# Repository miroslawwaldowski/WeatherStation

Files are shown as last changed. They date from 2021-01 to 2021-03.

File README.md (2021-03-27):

# Weather station Wi-Fi / GSM 

Application view            |  Device view
:-------------------------:|:-------------------------:
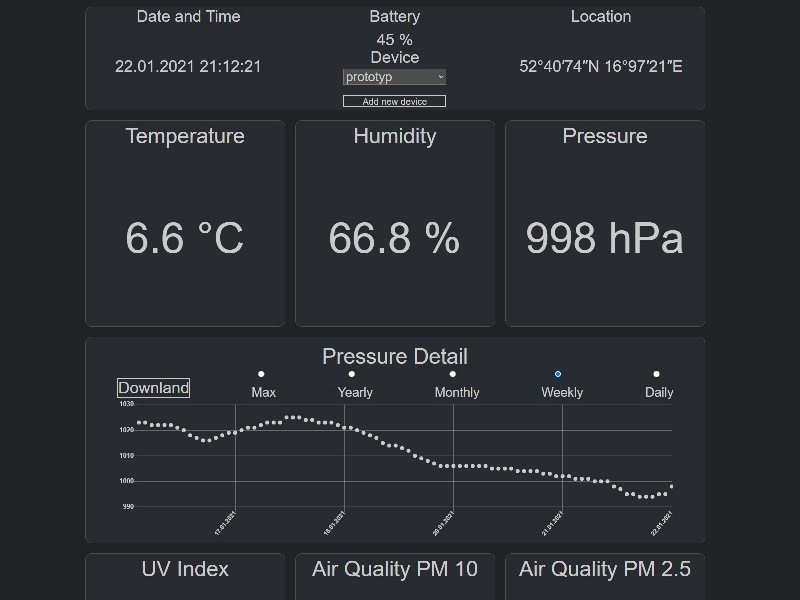
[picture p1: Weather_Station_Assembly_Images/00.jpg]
main app
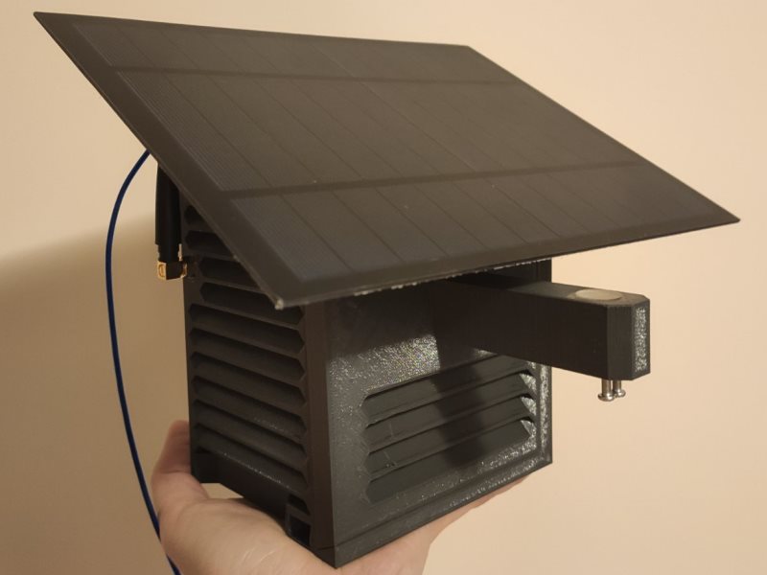
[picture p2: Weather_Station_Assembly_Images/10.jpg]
final view
 |  

## Introduction
The weather station project implemented as part of the Engineering Project at the Faculty of Mathematics and Computer Science of the University of Adam Mickiewicz in Poznań. The goal is to create a weather station based on an 8-bit microcontroller with a web application for collecting and presenting data. The station will have temperature, humidity, pressure, UV index and air quality sensors.
## Content

<p align="center">

folder / files          |  description
:-------------------------:|:-------------------------:
Tests/ |	Tests and results
Weather_Station_3D_Model/	| 3d model
Weather_Station_STL_file/	| 3d printing files
Weather_Station_Visualisation/	| 3d visualization
Weather_Station_Assembly_Images/	| Device assembly photos
Weather_Station_Wiring_Diagrams/	| Block and connections diagrams
client/	| React app
db/	| Database data schema and connection
device/	| Device software
index.js, app.js	| Node JS server

</p>

## Device

### Components
*	Arduino Nano board
*	communication module:
    * GSM - SIM800L EVB or  
    * WiFi - Wemos D1 Mini
*	temperature, humidity and pressure sensor BME280
*	Nova Fitness SDS011 dust sensor
*	UV sensor GUVA-S12SD
*	3.3V / 5V logic level converter
*	6V / 1A photovoltaic panel
*	NPN bipolar transistor, e.g. 2N2222
*	Schottky diode e.g. 1N5822
*	MT3608 step-up voltage converter
*	Li-Pol TP4056 charger with protection
*	2 x 18650 Li-Ion cells
*	4700uF capacitor
*	Universal double sided board

## Notes on device components

* SIM800L EVB module: due to the high instantaneous power consumption when establishing a connection to the GSM network, a capacitor with a capacity of at least 2000uF should be soldered to the module (photo below). Additionally, the module should have the [1418B05SIM800L24 firmware version](https://letmeknow.fr/blog/wp-content/uploads/2018/01/1418B05SIM800L24.zip). Software update instruction [link](http://www.raviyp.com/learn-how-to-update-the-firmware-of-your-sim800-modules/).

<p align="center">
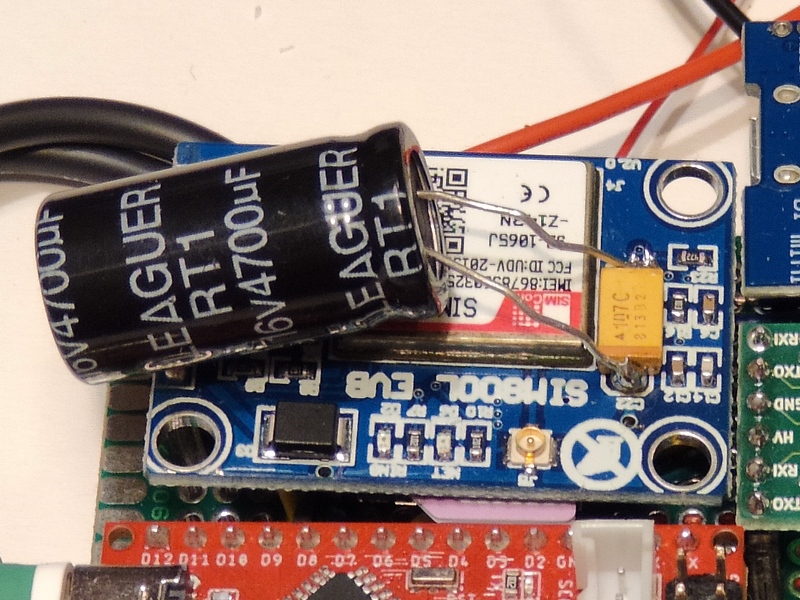
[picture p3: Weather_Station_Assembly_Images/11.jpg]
SIM800L
  
</p>

* Wemos D1 Mini module - the baud rate of serial communication data must be set to 9600. The change can be made with the command  `AT+CIOBAUD=9600`.  
* The MT3608 step-up voltage converter must have the output voltage set to 5V.

## Connection diagrams 
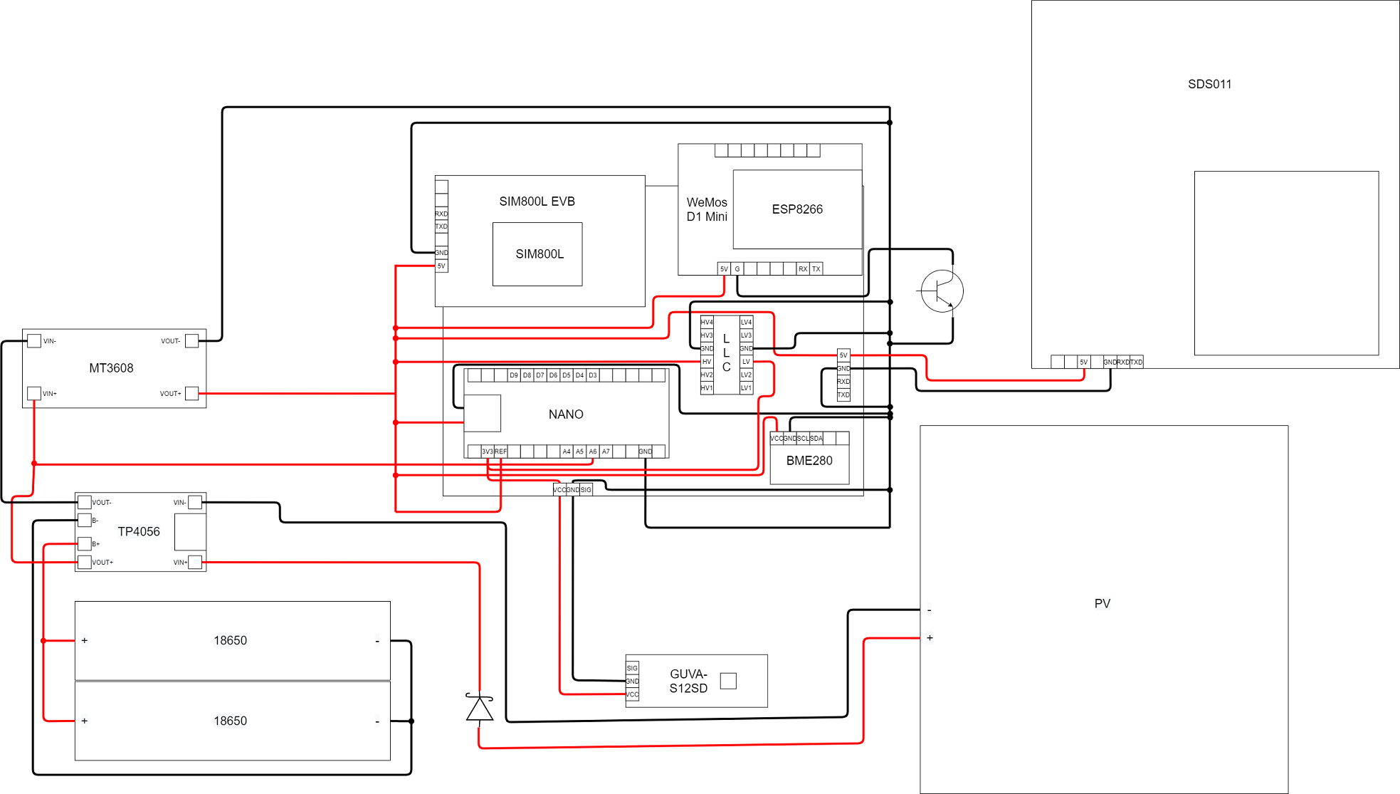
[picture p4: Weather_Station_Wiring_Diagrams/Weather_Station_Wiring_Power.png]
Wiring Power

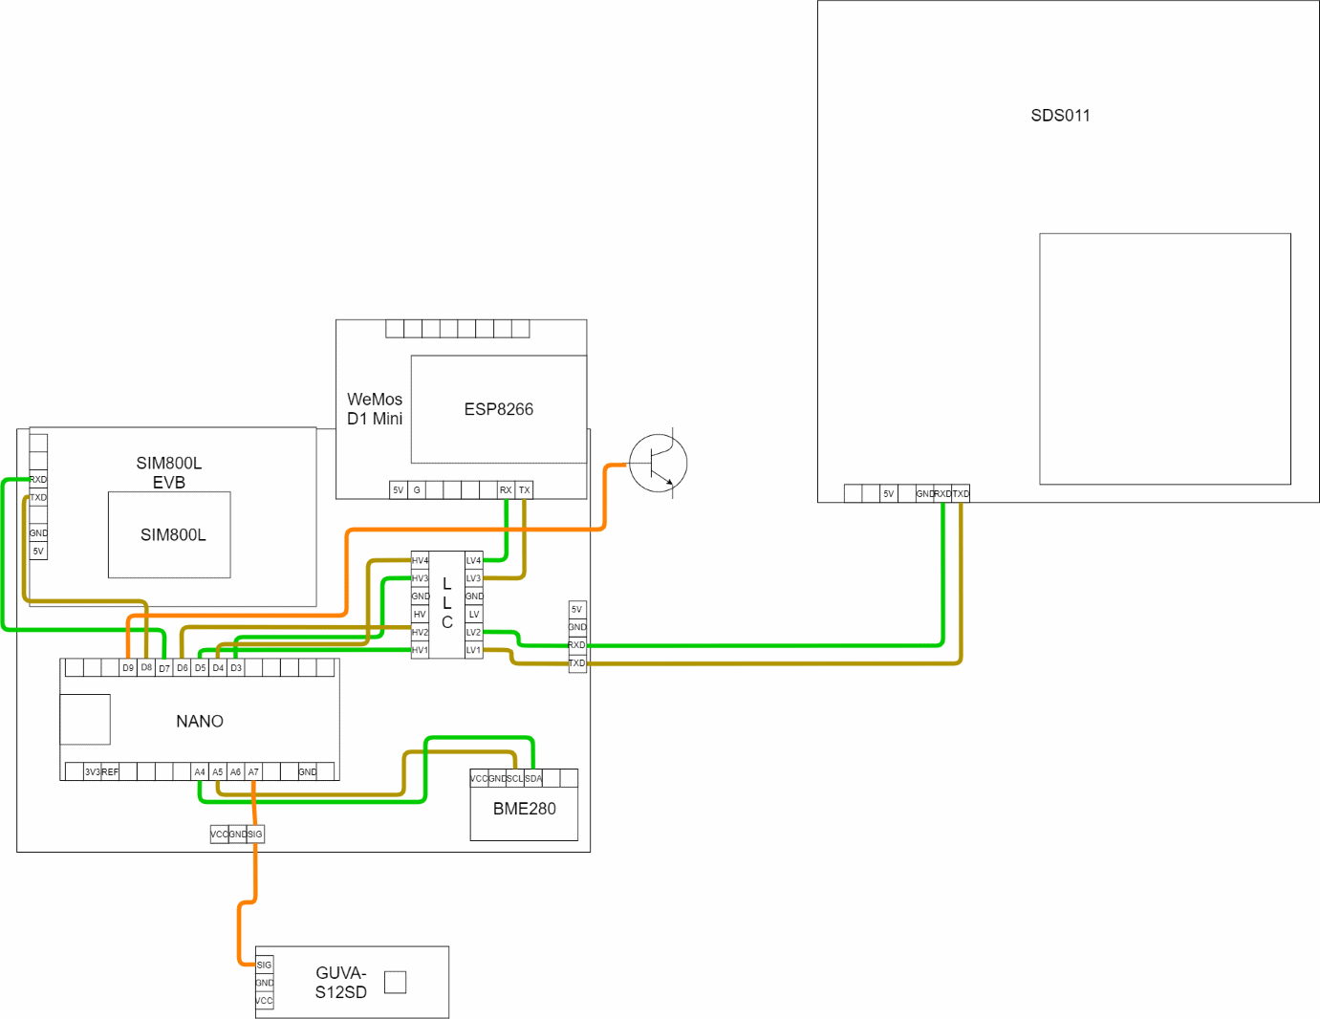
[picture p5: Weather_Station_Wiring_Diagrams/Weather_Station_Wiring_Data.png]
Wiring_Data


## Assembly of device elements

Picture of the assembled elements on the universal board according to the connection diagrams 
<p align="center">
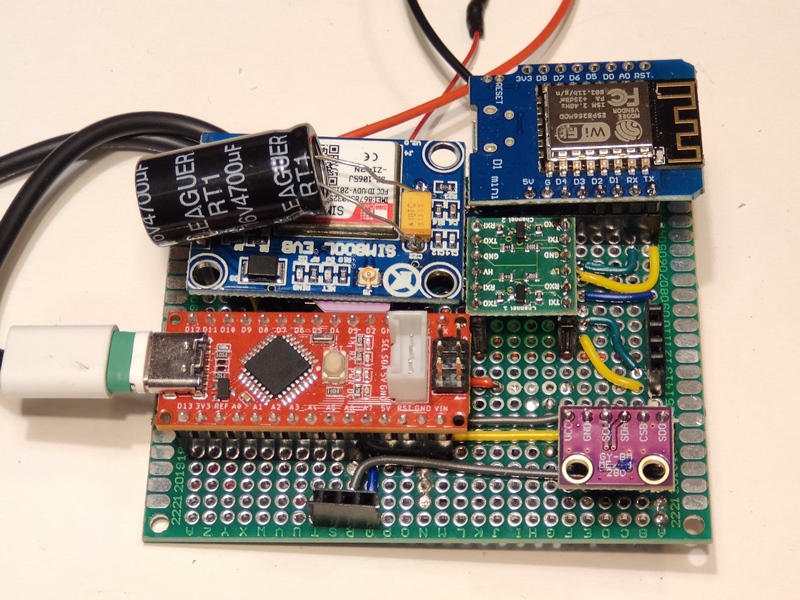
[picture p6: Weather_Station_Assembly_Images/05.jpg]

</p>

The next stages of assembly of elements in the case. The files for printing the case are in the Weather_Station_STL_file folder and the visualization of the arrangement of elements in the Weather_Station_Visualisation folder.

antenna assembly         |  battery assembly
:-------------------------:|:-------------------------:
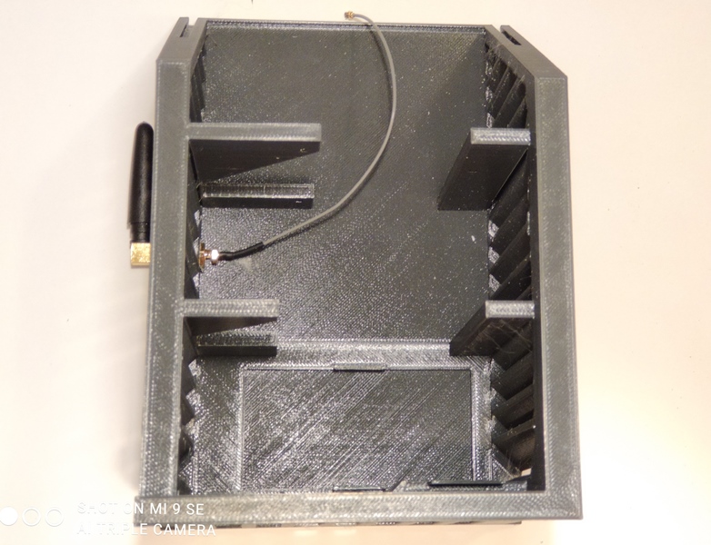
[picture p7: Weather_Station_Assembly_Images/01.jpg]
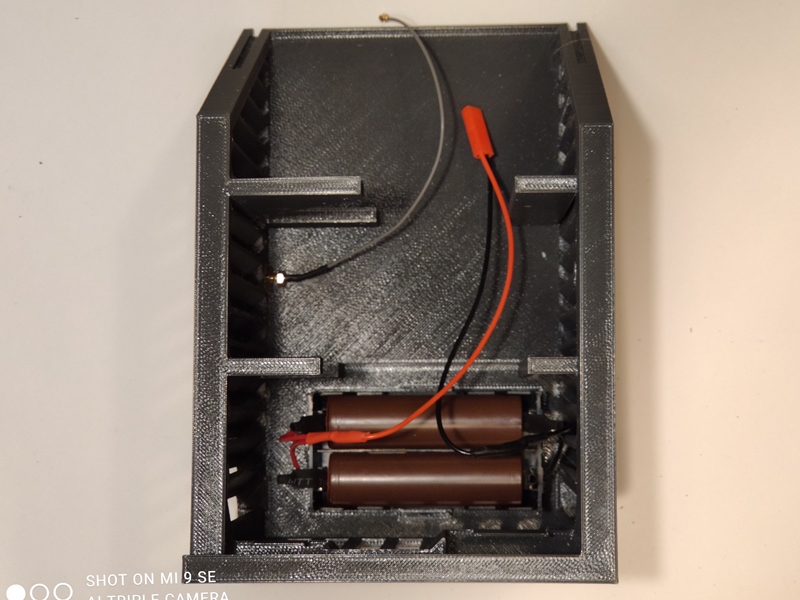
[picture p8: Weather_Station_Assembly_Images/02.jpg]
 |  
assembly of the Li-Po charger            |  voltage converter assembly
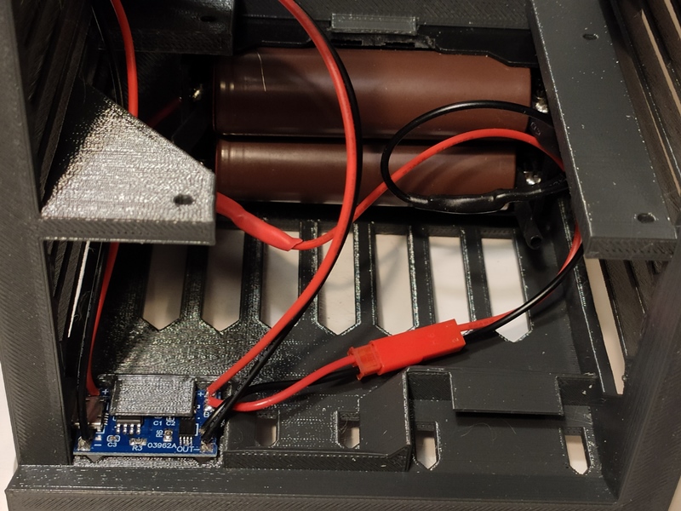
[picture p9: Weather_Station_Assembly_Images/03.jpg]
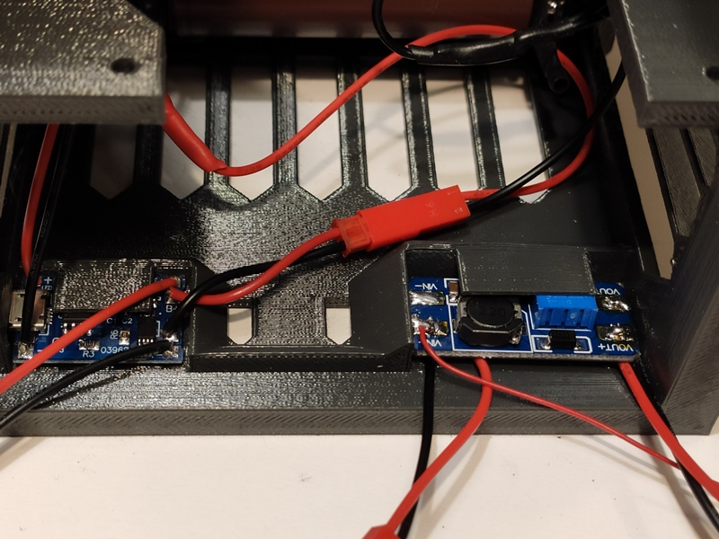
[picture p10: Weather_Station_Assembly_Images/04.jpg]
 |  
assembly of the plate with mounted elements             |  UV sensor assembly
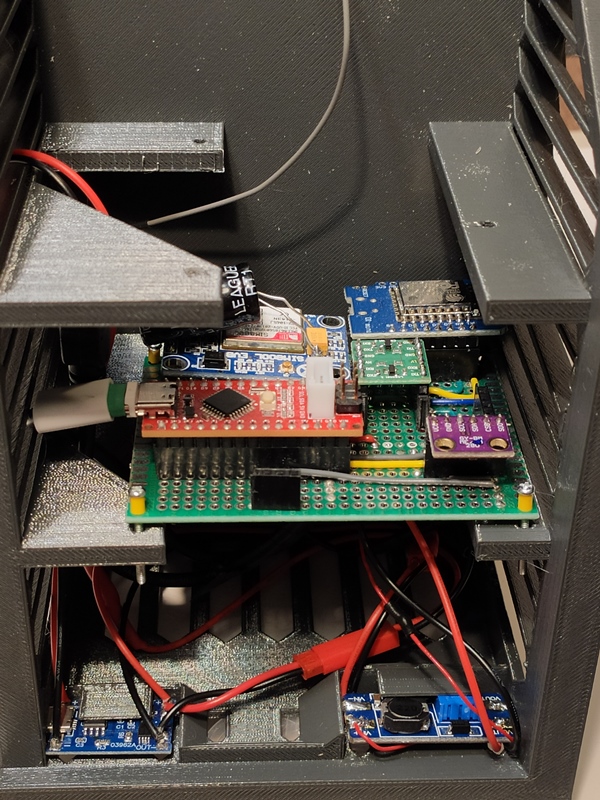
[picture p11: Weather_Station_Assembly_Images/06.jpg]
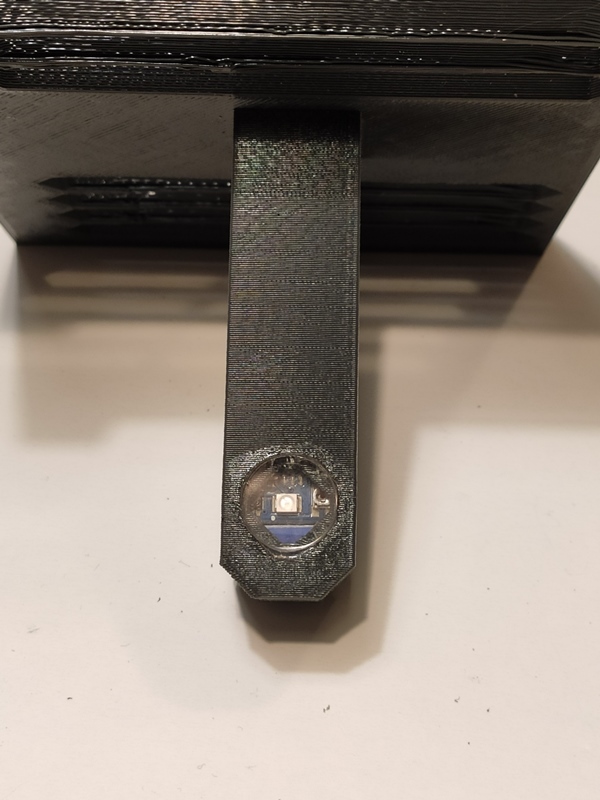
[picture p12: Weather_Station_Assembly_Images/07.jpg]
 |  
installation of a photovoltaic panel            |  Device view
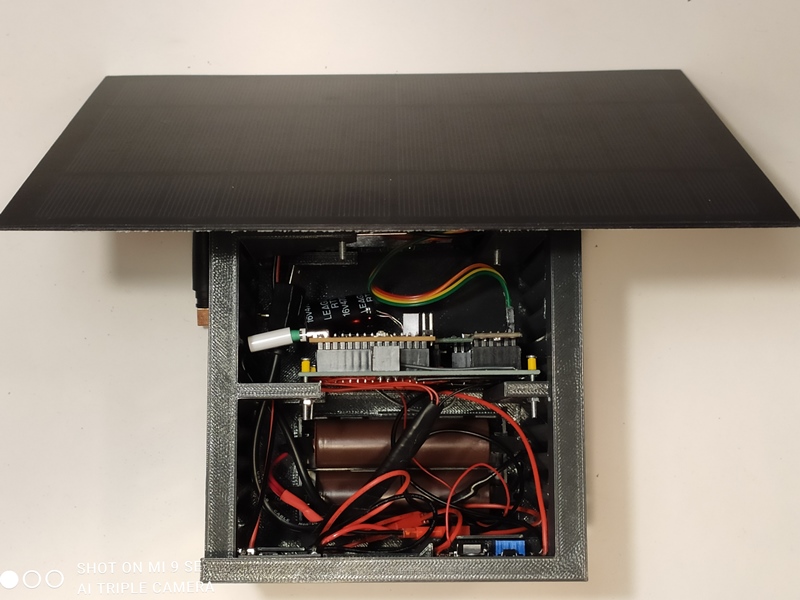
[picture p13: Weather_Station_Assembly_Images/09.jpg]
 |  

## Software
### Block diagram

<p align="center">
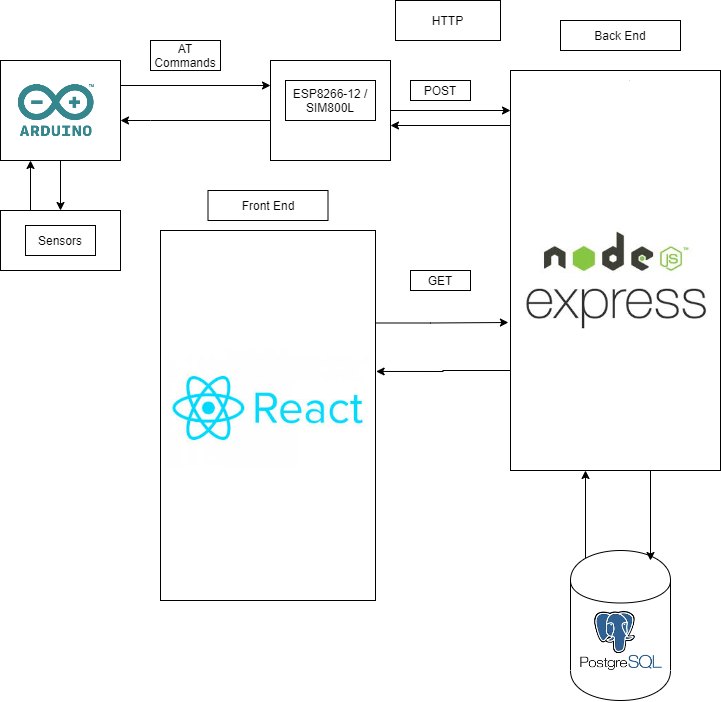
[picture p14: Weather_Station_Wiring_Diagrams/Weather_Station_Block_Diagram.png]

</p>

### Relational PostgreSQL database
ERD entity relationship diagram

<p align="center">
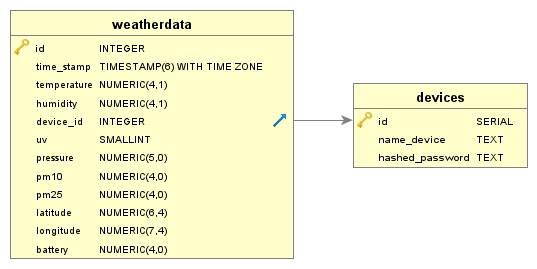
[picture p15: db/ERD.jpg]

</p>

`database.sql` file contains commands to generate SQL database.
An example of installing a database on an ElephantSQL server is available at [this link](https://www.learmoreseekmore.com/2020/09/postgresql-elephantsql-cloudserv.html).

## Mapbox Token

In order for maps with the device location to be displayed correctly in the application, you must obtain a token from the Mapbox website.
To do this, create a free account at [https://www.mapbox.com/](https://www.mapbox.com/).
After registering, your token will be visible in the "Account" tab, which will be needed to configure the React application.

## Installation of React application software and Node js server on the example of installation on the Heroku cloud platform

First, you need to clone the repository  
`$ git clone https://github.com/miroslawwaldowski/WeatherStation`  
Then create an account at [https://www.heroku.com/](https://www.heroku.com/) and install [Heroku CLI](https://devcenter.heroku.com/articles/heroku-command-line).  
After installation, go to the main application folder and log in to the Heroku   
`$ heroku login`  
The application on the server is created with the command  
`$ heroku create example`  
Where `example` is the name of our application. The application will be available at https://example.herokuapp.com/  
We add a remote Herock repository with the command   
`$ heroku git:remote -a example`  
Where `example` is the name of our application  
Finally, we approve the changes and send them  
`$ git add .`  
`$ git commit -am "version 1.0"`  
`$ git push heroku master`  
After completing the steps, the application should install on the website.  

## Environment variables for the app:

`DB_DATABASE=database name`  
`DB_HOST=database server`  
`DB_PASSWORD=database password`  
`DB_PORT=port to database`  
`DB_USER=database user`  
`REACT_APP_MAPBOX_TOKEN=token from Mapbox`  

## Installing the software on the Arduino Nano.

Before installing the software, the following libraries should be installed to the Arduino IDE 
[LowPower](https://github.com/rocketscream/Low-Power) and [Adafruit_BME280_Library](https://github.com/adafruit/Adafruit_BME280_Library) and configure the source code of the `device/app.ino` :

/*If DEBUG is true, it prints answers from the modem to Serial monitor*/  
`#define DEBUG true`  
/*If GSM is true, connect via GSM/GPRS, if false, connect via WiFi*/  
`#define GSM_MODE true`  
// configuration of the application address and port  
`const char server[] PROGMEM = {"your-application.com"};`  
`int port = 80;`  
// Wi-Fi configuration  
`const char ssid_WiFI[] PROGMEM = {"YOUR_SSID_NAME"};`  
`const char password_WiFI[] PROGMEM = {"YOUR_PASSWORD_TO_WIFI"};`  
// GPRS APN configuration of the mobile network  
`const char gprs_apn[] PROGMEM = {"\"INTERNET\""};`  
// data configuration of this device  
`const char device_name[] PROGMEM = {"OWN_DEVICE_NAME"};`  
`const char server_password[] PROGMEM = {"OWN_PASSWORD_ DEVICE"};`  
// device height above sea level in in meters for calculating relative pressure  
`int height_above_sea_level = 80;`  

## Final configuration.

After installing the software on the arduino board, the previously configured device should be added to the web application by entering the website of your application and clicking the `add new device` button. In the form that will appear, enter exactly the device name and password that were given in the device data configuration.

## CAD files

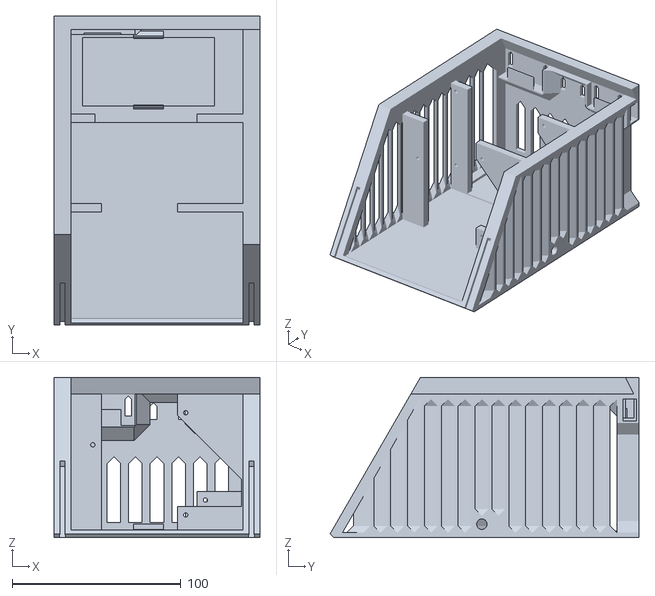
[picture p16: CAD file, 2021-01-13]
Weather_Station_STL_file/Weather_Station_ Body.stl
122.0 x 183.0 x 95.0

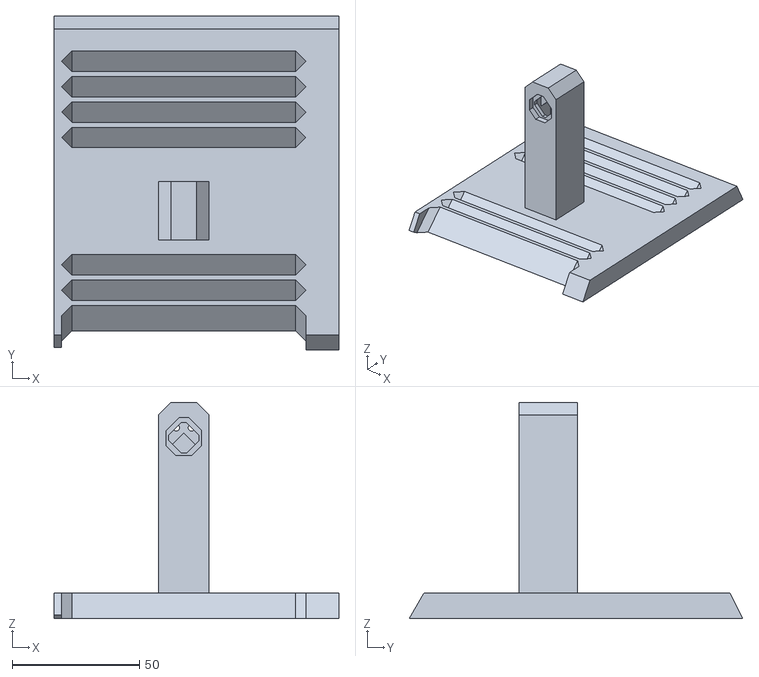
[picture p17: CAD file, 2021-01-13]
Weather_Station_STL_file/Weather_Station_Door.stl
112.0 x 131.2 x 85.0

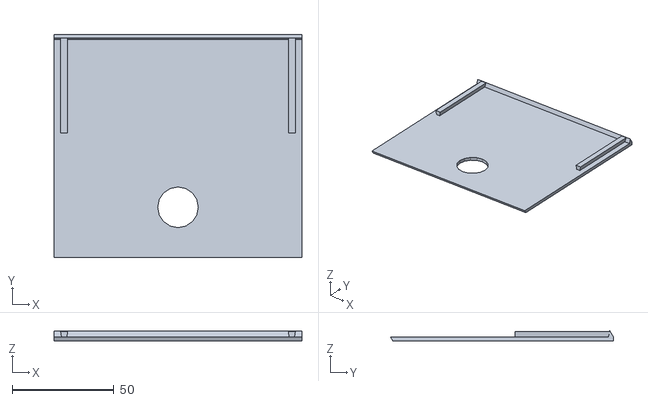
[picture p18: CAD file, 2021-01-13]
Weather_Station_STL_file/Weather_Station_ Roof.stl
122.0 x 109.7 x 5.00

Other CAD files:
Weather_Station_3D_Model/Weather_Station.skp

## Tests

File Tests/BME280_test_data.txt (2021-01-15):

16:27:54.086 -> Temperature C = 
16:27:54.086 -> 24.93
16:27:55.101 -> 24.93
16:27:56.097 -> 24.93
16:27:57.080 -> 24.93
16:27:58.103 -> 24.93
16:27:59.091 -> 24.93
16:28:00.078 -> 24.93
16:28:01.102 -> 24.92
16:28:02.134 -> 24.92
16:28:03.080 -> 24.92
16:28:04.119 -> 24.92
16:28:05.128 -> 24.93
16:28:06.103 -> 24.93
16:28:07.103 -> 24.93
16:28:08.132 -> 24.93
16:28:09.148 -> 24.93
16:28:10.132 -> 24.93
16:28:11.111 -> 24.92
16:28:12.136 -> 24.92
16:28:13.126 -> 24.92
16:28:14.146 -> 24.92
16:28:15.113 -> 24.92
16:28:16.153 -> 24.91
16:28:17.124 -> 24.91
16:28:18.142 -> 24.91
16:28:19.131 -> 24.91
16:28:20.128 -> 24.90
16:28:21.154 -> 24.89
16:28:22.136 -> 24.89
16:28:23.155 -> 24.89
16:28:24.148 -> 24.89
16:28:25.152 -> 24.88
16:28:26.167 -> 24.89
16:28:27.120 -> 24.88
16:28:28.166 -> 24.88
16:28:29.143 -> 24.87
16:28:30.139 -> 24.87
16:28:31.171 -> 24.87
16:28:32.156 -> 24.87
16:28:33.179 -> 24.87
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
16:29:34.266 -> Humidity % = 
16:29:34.266 -> 31.08
16:29:35.277 -> 31.09
16:29:36.279 -> 31.04
16:29:37.273 -> 31.03
16:29:38.283 -> 31.08
16:29:39.293 -> 31.10
16:29:40.286 -> 31.10
16:29:41.291 -> 31.11
16:29:42.310 -> 31.23
16:29:43.302 -> 31.26
16:29:44.322 -> 31.27
16:29:45.298 -> 31.25
16:29:46.293 -> 31.21
16:29:47.303 -> 31.27
16:29:48.300 -> 31.20
16:29:49.323 -> 31.16
16:29:50.319 -> 31.13
16:29:51.296 -> 31.13
16:29:52.334 -> 31.14
16:29:53.308 -> 31.16
16:29:54.296 -> 31.19
16:29:55.319 -> 31.25
16:29:56.329 -> 31.29
16:29:57.324 -> 31.35
16:29:58.326 -> 31.41
16:29:59.340 -> 31.48
16:30:00.351 -> 32.06
16:30:01.450 -> 32.36
16:30:02.327 -> 32.61
16:30:03.318 -> 32.56
16:30:04.341 -> 32.57
16:30:05.361 -> 32.47
16:30:06.331 -> 32.42
16:30:07.368 -> 32.36
16:30:08.374 -> 32.30
16:30:09.367 -> 32.42
16:30:10.346 -> 32.60
16:30:11.370 -> 32.48
16:30:12.349 -> 32.24
16:30:13.372 -> 32.03
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
16:31:14.526 -> Pressure hPa = 
16:31:14.526 -> 1009.23
16:31:15.504 -> 1009.24
16:31:16.542 -> 1009.26
16:31:17.520 -> 1009.27
16:31:18.510 -> 1009.27
16:31:19.540 -> 1009.25
16:31:20.539 -> 1009.26
16:31:21.519 -> 1009.28
16:31:22.520 -> 1009.29
16:31:23.537 -> 1009.29
16:31:24.521 -> 1009.31
16:31:25.526 -> 1009.35
16:31:26.537 -> 1009.30
16:31:27.562 -> 1009.29
16:31:28.578 -> 1009.27
16:31:29.563 -> 1009.29
16:31:30.559 -> 1009.28
16:31:31.573 -> 1009.30
16:31:32.576 -> 1009.31
16:31:33.573 -> 1009.31
16:31:34.587 -> 1009.31
16:31:35.571 -> 1009.30
16:31:36.605 -> 1009.25
16:31:37.580 -> 1009.29
16:31:38.604 -> 1009.28
16:31:39.584 -> 1009.26
16:31:40.600 -> 1009.28
16:31:41.580 -> 1009.27
16:31:42.610 -> 1009.31
16:31:43.594 -> 1009.27
16:31:44.619 -> 1009.27
16:31:45.604 -> 1009.31
16:31:46.620 -> 1009.29
16:31:47.605 -> 1009.26
16:31:48.635 -> 1009.29
16:31:49.620 -> 1009.29
16:31:50.605 -> 1009.26
16:31:51.638 -> 1009.30
16:31:52.622 -> 1009.25
16:31:53.610 -> 1009.26
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

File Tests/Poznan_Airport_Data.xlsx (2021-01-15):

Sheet: Arkusz1
Time | Temperature | Humidity | Pressure
 | C | % | hPa
2021-01-12 01:00 | 0 | 74 | 1010
2021-01-12 02:00 | 0 | 80 | 1008
2021-01-12 02:30 | 0 | 74 | 1008
2021-01-12 03:00 | 0 | 80 | 1008
2021-01-12 03:01 | 0 | 80 | 1008
2021-01-12 03:30 | 0 | 80 | 1007
2021-01-12 04:00 | 0 | 80 | 1006
2021-01-12 04:30 | 0 | 80 | 1006
2021-01-12 05:00 | 0 | 80 | 1005
2021-01-12 05:01 | 0 | 80 | 1005
2021-01-12 05:30 | 1 | 75 | 1005
2021-01-12 06:00 | 1 | 75 | 1005
2021-01-12 06:30 | 1 | 80 | 1004
2021-01-12 07:00 | 1 | 80 | 1004
2021-01-12 07:31 | 1 | 80 | 1004
2021-01-12 07:30 | 1 | 80 | 1004
2021-01-12 08:00 | 0 | 86 | 1004
2021-01-12 08:30 | 0 | 93 | 1003
2021-01-12 09:00 | 0 | 93 | 1003
2021-01-12 09:30 | 0 | 93 | 1003
2021-01-12 10:00 | 0 | 93 | 1003
2021-01-12 10:30 | 0 | 93 | 1002
2021-01-12 10:31 | 0 | 93 | 1002
2021-01-12 11:00 | 0 | 93 | 1002
2021-01-12 11:30 | 0 | 93 | 1001
2021-01-12 12:00 | 0 | 93 | 1001
2021-01-12 12:30 | 0 | 93 | 1001
2021-01-12 12:31 | 0 | 93 | 1001
2021-01-12 13:00 | 0 | 100 | 1000
2021-01-12 13:30 | 0 | 100 | 1000
2021-01-12 14:00 | 0 | 100 | 1000
2021-01-12 14:01 | 0 | 100 | 1000
2021-01-12 14:31 | 0 | 100 | 1000
2021-01-12 14:30 | 0 | 100 | 1000
2021-01-12 15:00 | 0 | 100 | 1000
2021-01-12 15:31 | 0 | 100 | 1000
2021-01-12 16:00 | 0 | 100 | 1000
2021-01-12 16:30 | 0 | 100 | 1000
2021-01-12 17:00 | 0 | 100 | 999
2021-01-12 17:01 | 0 | 100 | 999
2021-01-12 17:30 | 0 | 100 | 999
2021-01-12 18:00 | 0 | 100 | 1000
2021-01-12 18:30 | 0 | 100 | 1000
2021-01-12 19:00 | 0 | 100 | 1000
2021-01-12 19:30 | 0 | 100 | 1001
2021-01-12 20:00 | 0 | 100 | 1001
2021-01-12 20:30 | 0 | 100 | 1002
2021-01-12 21:00 | 0 | 93 | 1002
2021-01-12 21:30 | 0 | 93 | 1002
2021-01-12 22:01 | 0 | 93 | 1002
2021-01-12 22:00 | 0 | 93 | 1002
2021-01-12 22:31 | 0 | 93 | 1003
2021-01-12 22:30 | 0 | 93 | 1003
2021-01-12 23:00 | 0 | 93 | 1002
2021-01-12 23:30 | 0 | 93 | 1003
2021-01-13 00:01 | 0 | 100 | 1003
2021-01-13 | 0 | 100 | 1003
2021-01-13 00:30 | 0 | 100 | 1003
2021-01-13 00:31 | 0 | 100 | 1003
2021-01-13 01:00 | 0 | 100 | 1003
2021-01-13 01:30 | 0 | 93 | 1004
2021-01-13 02:00 | 0 | 93 | 1004
2021-01-13 02:30 | 0 | 93 | 1004
2021-01-13 03:01 | 0 | 93 | 1004
2021-01-13 03:00 | 0 | 93 | 1004
2021-01-13 03:30 | 0 | 93 | 1005
2021-01-13 04:00 | 0 | 93 | 1005
2021-01-13 04:30 | 0 | 93 | 1005
2021-01-13 05:01 | 0 | 93 | 1005
2021-01-13 05:00 | 0 | 93 | 1005
2021-01-13 05:30 | 0 | 93 | 1005
2021-01-13 05:31 | 0 | 93 | 1005
2021-01-13 06:00 | 0 | 93 | 1005
2021-01-13 06:30 | 0 | 93 | 1005
2021-01-13 07:00 | 0 | 93 | 1005
2021-01-13 07:30 | 0 | 100 | 1006
2021-01-13 08:00 | 0 | 100 | 1006
2021-01-13 08:30 | 0 | 100 | 1006
2021-01-13 09:00 | 1 | 86 | 1006
2021-01-13 09:30 | 1 | 86 | 1006
2021-01-13 10:00 | 1 | 86 | 1006
2021-01-13 10:30 | 1 | 93 | 1006
2021-01-13 11:00 | 1 | 93 | 1006
2021-01-13 11:30 | 1 | 93 | 1006
2021-01-13 12:00 | 1 | 93 | 1005
2021-01-13 12:30 | 1 | 93 | 1005
2021-01-13 13:00 | 1 | 93 | 1005
2021-01-13 13:30 | 1 | 93 | 1005
2021-01-13 14:00 | 1 | 93 | 1005
2021-01-13 14:01 | 1 | 93 | 1005
2021-01-13 14:30 | 1 | 93 | 1005
2021-01-13 14:31 | 1 | 93 | 1005
2021-01-13 15:00 | 1 | 93 | 1005
2021-01-13 15:30 | 1 | 93 | 1004
2021-01-13 16:00 | 1 | 93 | 1004
2021-01-13 16:30 | 1 | 93 | 1004
2021-01-13 17:00 | 1 | 93 | 1003
2021-01-13 17:30 | 1 | 93 | 1003
2021-01-13 18:00 | 1 | 93 | 1003
2021-01-13 18:30 | 1 | 93 | 1002
2021-01-13 19:00 | 1 | 93 | 1002
2021-01-13 19:30 | 0 | 100 | 1001
2021-01-13 20:00 | 0 | 100 | 1001
2021-01-13 20:01 | 0 | 100 | 1001
2021-01-13 20:30 | 0 | 100 | 1000
2021-01-13 21:00 | 0 | 100 | 1000
2021-01-13 21:30 | 0 | 100 | 1000
2021-01-13 22:00 | 0 | 100 | 1000
2021-01-13 22:01 | 0 | 100 | 1000
2021-01-13 22:30 | 0 | 100 | 1000
2021-01-13 23:00 | 0 | 100 | 1000
2021-01-13 23:30 | 0 | 100 | 1000
2021-01-14 | 0 | 100 | 1000
2021-01-14 00:30 | 0 | 100 | 1000
2021-01-14 01:00 | 0 | 100 | 1001
2021-01-14 01:30 | 0 | 100 | 1001
2021-01-14 02:00 | 0 | 100 | 1001
2021-01-14 02:30 | 0 | 100 | 1002
2021-01-14 03:00 | 0 | 100 | 1002
2021-01-14 04:01 | 0 | 100 | 1003
2021-01-14 04:00 | 0 | 100 | 1003
2021-01-14 04:30 | 0 | 100 | 1004
2021-01-14 05:00 | 0 | 100 | 1004
2021-01-14 05:30 | 0 | 100 | 1005
2021-01-14 06:00 | 0 | 100 | 1006
2021-01-14 06:30 | 0 | 100 | 1007
2021-01-14 07:00 | 0 | 100 | 1007
2021-01-14 07:30 | 0 | 100 | 1008
2021-01-14 08:00 | 0 | 100 | 1009
2021-01-14 08:01 | 0 | 100 | 1009
2021-01-14 08:30 | 0 | 100 | 1010
2021-01-14 09:00 | 0 | 93 | 1010
2021-01-14 09:30 | 0 | 93 | 1011
2021-01-14 10:00 | 0 | 93 | 1011
2021-01-14 10:30 | 0 | 93 | 1012
2021-01-14 11:00 | 0 | 93 | 1012
2021-01-14 11:30 | 0 | 93 | 1012
2021-01-14 12:00 | 0 | 93 | 1012
2021-01-14 12:30 | 0 | 93 | 1012
2021-01-14 13:00 | 0 | 93 | 1012
2021-01-14 13:30 | 0 | 100 | 1013
2021-01-14 14:00 | 0 | 100 | 1013
2021-01-14 14:01 | 0 | 100 | 1013
2021-01-14 15:00 | 0 | 100 | 1014
2021-01-14 15:30 | 0 | 93 | 1015
2021-01-14 16:00 | 0 | 93 | 1015
2021-01-14 16:30 | 0 | 93 | 1015
2021-01-14 17:00 | 0 | 93 | 1015
2021-01-14 17:30 | 0 | 93 | 1015
2021-01-14 18:00 | 0 | 93 | 1016
2021-01-14 18:30 | 0 | 93 | 1016
2021-01-14 18:31 | 0 | 93 | 1016
2021-01-14 19:00 | -1 | 93 | 1016
2021-01-14 19:30 | -1 | 93 | 1016
2021-01-14 20:00 | -1 | 93 | 1017
2021-01-14 20:30 | -1 | 86 | 1017
2021-01-14 21:00 | -1 | 86 | 1017
2021-01-14 21:30 | -1 | 93 | 1017
2021-01-14 22:00 | -1 | 93 | 1017
2021-01-14 22:30 | -1 | 100 | 1017
2021-01-14 23:00 | -1 | 100 | 1017
2021-01-14 23:30 | -1 | 100 | 1017
2021-01-15 | -1 | 100 | 1017
2021-01-15 00:01 | -1 | 100 | 1017
2021-01-15 01:00 | -1 | 100 | 1017
2021-01-15 01:30 | -1 | 100 | 1017
2021-01-15 02:00 | -1 | 93 | 1018
2021-01-15 02:30 | -1 | 93 | 1017
2021-01-15 03:00 | -1 | 93 | 1018
2021-01-15 03:30 | -1 | 93 | 1018
2021-01-15 04:01 | -2 | 100 | 1018
2021-01-15 04:00 | -2 | 100 | 1018
2021-01-15 04:30 | -2 | 100 | 1018
2021-01-15 05:00 | -2 | 100 | 1018
2021-01-15 05:30 | -2 | 100 | 1018
2021-01-15 06:00 | -2 | 100 | 1018
2021-01-15 06:31 | -2 | 100 | 1018
2021-01-15 06:30 | -2 | 100 | 1018
2021-01-15 07:00 | -2 | 93 | 1018
2021-01-15 07:30 | -2 | 100 | 1018
2021-01-15 08:00 | -2 | 100 | 1019
2021-01-15 08:30 | -1 | 93 | 1018
2021-01-15 09:00 | -1 | 93 | 1019
2021-01-15 09:30 | -1 | 93 | 1019
2021-01-15 10:00 | -1 | 93 | 1019
2021-01-15 10:30 | -1 | 93 | 1019
2021-01-15 11:00 | -1 | 86 | 1019
2021-01-15 11:30 | 0 | 86 | 1019
2021-01-15 12:00 | 0 | 86 | 1019
2021-01-15 12:30 | 0 | 86 | 1019
2021-01-15 13:00 | -1 | 86 | 1019
2021-01-15 13:31 | -1 | 86 | 1019
2021-01-15 13:30 | -1 | 86 | 1019
2021-01-15 14:00 | -1 | 86 | 1020
2021-01-15 14:30 | -1 | 86 | 1020
2021-01-15 14:31 | -1 | 86 | 1020
2021-01-15 15:00 | -1 | 86 | 1020
2021-01-15 15:30 | -1 | 93 | 1020
2021-01-15 16:00 | -2 | 93 | 1020
2021-01-15 16:30 | -2 | 93 | 1020
2021-01-15 16:31 | -2 | 93 | 1020
2021-01-15 17:00 | -2 | 86 | 1021
2021-01-15 17:30 | -2 | 86 | 1021
2021-01-15 18:00 | -2 | 86 | 1021
2021-01-15 18:31 | -2 | 86 | 1021

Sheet: Arkusz2
2021-01-12 01:00
2021-01-12 02:00
2021-01-12 02:30
2021-01-12 03:00
2021-01-12 03:01
2021-01-12 03:30
2021-01-12 04:00
2021-01-12 04:30
2021-01-12 05:00
2021-01-12 05:01
2021-01-12 05:30
2021-01-12 06:00
2021-01-12 06:30
2021-01-12 07:00
2021-01-12 07:31
2021-01-12 07:30
2021-01-12 08:00
2021-01-12 08:30
2021-01-12 09:00
2021-01-12 09:30
2021-01-12 10:00
2021-01-12 10:30
2021-01-12 10:31
2021-01-12 11:00
2021-01-12 11:30
2021-01-12 12:00
2021-01-12 12:30
2021-01-12 12:31
2021-01-12 13:00
2021-01-12 13:30
2021-01-12 14:00
2021-01-12 14:01
2021-01-12 14:31
2021-01-12 14:30
2021-01-12 15:00
2021-01-12 15:31
2021-01-12 16:00
2021-01-12 16:30
2021-01-12 17:00
2021-01-12 17:01
2021-01-12 17:30
2021-01-12 18:00
2021-01-12 18:30
2021-01-12 19:00
2021-01-12 19:30
2021-01-12 20:00
2021-01-12 20:30
2021-01-12 21:00
2021-01-12 21:30
2021-01-12 22:01
2021-01-12 22:00
2021-01-12 22:31
2021-01-12 22:30
2021-01-12 23:00
2021-01-12 23:30
2021-01-13 00:01
2021-01-13 00:00
2021-01-13 00:30
2021-01-13 00:31
2021-01-13 01:00
2021-01-13 01:30
2021-01-13 02:00
2021-01-13 02:30
2021-01-13 03:01
2021-01-13 03:00
2021-01-13 03:30
2021-01-13 04:00
2021-01-13 04:30
2021-01-13 05:01
2021-01-13 05:00
2021-01-13 05:30
2021-01-13 05:31
2021-01-13 06:00
2021-01-13 06:30
2021-01-13 07:00
2021-01-13 07:30
2021-01-13 08:00
2021-01-13 08:30
2021-01-13 09:00
2021-01-13 09:30
2021-01-13 10:00
2021-01-13 10:30
2021-01-13 11:00
2021-01-13 11:30
2021-01-13 12:00
2021-01-13 12:30
2021-01-13 13:00
2021-01-13 13:30
2021-01-13 14:00
2021-01-13 14:01
2021-01-13 14:30
2021-01-13 14:31
2021-01-13 15:00
2021-01-13 15:30
2021-01-13 16:00
2021-01-13 16:30
2021-01-13 17:00
2021-01-13 17:30
2021-01-13 18:00
2021-01-13 18:30
2021-01-13 19:00
2021-01-13 19:30
2021-01-13 20:00
2021-01-13 20:01
2021-01-13 20:30
2021-01-13 21:00
2021-01-13 21:30
2021-01-13 22:00
2021-01-13 22:01
2021-01-13 22:30
2021-01-13 23:00
2021-01-13 23:30
2021-01-14 00:00
2021-01-14 00:30
2021-01-14 01:00
2021-01-14 01:30
2021-01-14 02:00
2021-01-14 02:30
2021-01-14 03:00
2021-01-14 04:01
2021-01-14 04:00
2021-01-14 04:30
2021-01-14 05:00
2021-01-14 05:30
2021-01-14 06:00
2021-01-14 06:30
2021-01-14 07:00
2021-01-14 07:30
2021-01-14 08:00
2021-01-14 08:01
2021-01-14 08:30
2021-01-14 09:00
2021-01-14 09:30
2021-01-14 10:00
2021-01-14 10:30
2021-01-14 11:00
2021-01-14 11:30
2021-01-14 12:00
2021-01-14 12:30
2021-01-14 13:00
2021-01-14 13:30
2021-01-14 14:00
2021-01-14 14:01
2021-01-14 15:00
2021-01-14 15:30
2021-01-14 16:00
2021-01-14 16:30
2021-01-14 17:00
2021-01-14 17:30
2021-01-14 18:00
2021-01-14 18:30
2021-01-14 18:31
2021-01-14 19:00
2021-01-14 19:30
2021-01-14 20:00
2021-01-14 20:30
2021-01-14 21:00
2021-01-14 21:30
2021-01-14 22:00
2021-01-14 22:30
2021-01-14 23:00
2021-01-14 23:30
2021-01-15 00:00
2021-01-15 00:01
2021-01-15 01:00
2021-01-15 01:30
2021-01-15 02:00
2021-01-15 02:30
2021-01-15 03:00
2021-01-15 03:30
2021-01-15 04:01
2021-01-15 04:00
2021-01-15 04:30
2021-01-15 05:00
2021-01-15 05:30
2021-01-15 06:00
2021-01-15 06:31
2021-01-15 06:30
2021-01-15 07:00
2021-01-15 07:30
2021-01-15 08:00
2021-01-15 08:30
2021-01-15 09:00
2021-01-15 09:30
2021-01-15 10:00
2021-01-15 10:30
2021-01-15 11:00
2021-01-15 11:30
2021-01-15 12:00
2021-01-15 12:30
2021-01-15 13:00
2021-01-15 13:31
2021-01-15 13:30
2021-01-15 14:00
2021-01-15 14:30
2021-01-15 14:31
2021-01-15 15:00
2021-01-15 15:30
2021-01-15 16:00
2021-01-15 16:30
2021-01-15 16:31
2021-01-15 17:00
2021-01-15 17:30
2021-01-15 18:00
2021-01-15 18:31

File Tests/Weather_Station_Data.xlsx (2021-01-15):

Time | Temperature | Humidity | Pressure | Temperature Error | Humidity Error | Pressure Error
 | C | % | hPa | C | % | hPa
2021-01-15 21:40 | -3.5 | 79.9 | 1023 | 1.25 | 3 | 1.7
2021-01-15 20:41 | -3.2 | 78.5 | 1023 | 1.25 | 3 | 1.7
2021-01-15 19:41 | -2.2 | 77.4 | 1023 | 1.25 | 3 | 1.7
2021-01-15 18:41 | -2 | 75.5 | 1022 | 1.25 | 3 | 1.7
2021-01-15 17:41 | -1.4 | 74.4 | 1022 | 1.25 | 3 | 1.7
2021-01-15 16:42 | -1.3 | 76.9 | 1022 | 1.25 | 3 | 1.7
2021-01-15 15:42 | -0.9 | 79.4 | 1021 | 1.25 | 3 | 1.7
2021-01-15 14:42 | 0.1 | 75.4 | 1021 | 1 | 3 | 1
2021-01-15 13:42 | 1.3 | 71.2 | 1020 | 1 | 3 | 1
2021-01-15 12:42 | 0.5 | 69.5 | 1020 | 1 | 3 | 1
2021-01-15 10:43 | 1.1 | 71.1 | 1020 | 1 | 3 | 1
2021-01-15 08:43 | 0.1 | 78.8 | 1020 | 1 | 3 | 1
2021-01-15 07:44 | -0.3 | 78.3 | 1020 | 1 | 3 | 1
2021-01-15 06:44 | -1.2 | 79.2 | 1019 | 1.25 | 3 | 1.7
2021-01-15 05:44 | -1.1 | 79.4 | 1019 | 1.25 | 3 | 1.7
2021-01-15 04:44 | -0.8 | 79.5 | 1019 | 1.25 | 3 | 1.7
2021-01-15 03:44 | -0.5 | 80.8 | 1019 | 1.25 | 3 | 1.7
2021-01-15 02:45 | -0.6 | 82.7 | 1019 | 1.25 | 3 | 1.7
2021-01-15 01:45 | -0.6 | 83.1 | 1019 | 1.25 | 3 | 1.7
2021-01-15 00:45 | -0.2 | 81.2 | 1019 | 1.25 | 3 | 1.7
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

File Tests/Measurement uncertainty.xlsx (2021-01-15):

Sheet: Temperatura
Nr. pomiaru | Wartość Tn | Wartość średnia Tś | (Tn-Tś)^2 | Odchylenie standardowe średniej | Niepewność standardowa średniej | Rozdzielczość przyrządu | Niepewność związana z rozdzielczością | Niepewność złożona | Niepewność rozszeżona | Wynik pomiaru
1 | 24.93 | 24.8558 | 0.00550564 | 0.0473154042 | 0.00473154042 | 0.01 | 0.002886751346 | 0.005542635482 | 0.01662790644 | 24,86 ± 0,02
2 | 24.93 |  | 0.00550564
3 | 24.93 |  | 0.00550564
4 | 24.93 |  | 0.00550564
5 | 24.93 |  | 0.00550564
6 | 24.93 |  | 0.00550564
7 | 24.93 |  | 0.00550564
8 | 24.92 |  | 0.00412164
9 | 24.92 |  | 0.00412164
10 | 24.92 |  | 0.00412164
11 | 24.92 |  | 0.00412164
12 | 24.93 |  | 0.00550564
13 | 24.93 |  | 0.00550564
14 | 24.93 |  | 0.00550564
15 | 24.93 |  | 0.00550564
16 | 24.93 |  | 0.00550564
17 | 24.93 |  | 0.00550564
18 | 24.92 |  | 0.00412164
19 | 24.92 |  | 0.00412164
20 | 24.92 |  | 0.00412164
21 | 24.92 |  | 0.00412164
22 | 24.92 |  | 0.00412164
23 | 24.91 |  | 0.00293764
24 | 24.91 |  | 0.00293764
25 | 24.91 |  | 0.00293764
26 | 24.91 |  | 0.00293764
27 | 24.9 |  | 0.00195364
28 | 24.89 |  | 0.00116964
29 | 24.89 |  | 0.00116964
30 | 24.89 |  | 0.00116964
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

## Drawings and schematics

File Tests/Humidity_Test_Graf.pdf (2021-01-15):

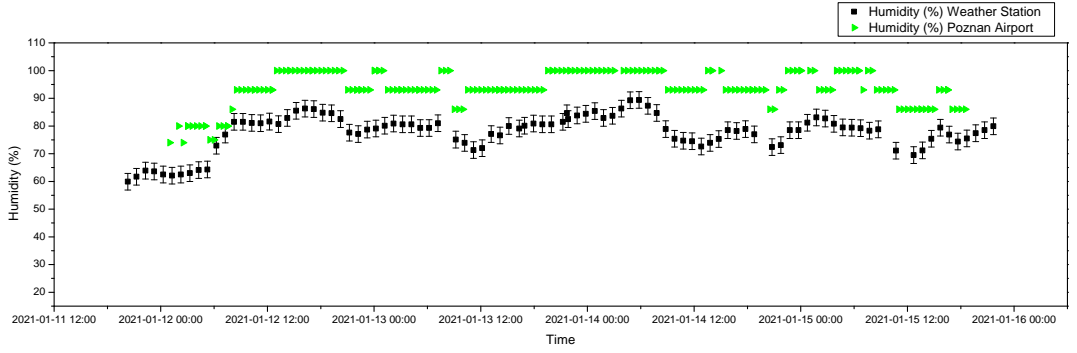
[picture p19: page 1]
Tim e

H um i di ty (%) Weath er Stati on
H um i di ty (%) Pozn an Ai rport

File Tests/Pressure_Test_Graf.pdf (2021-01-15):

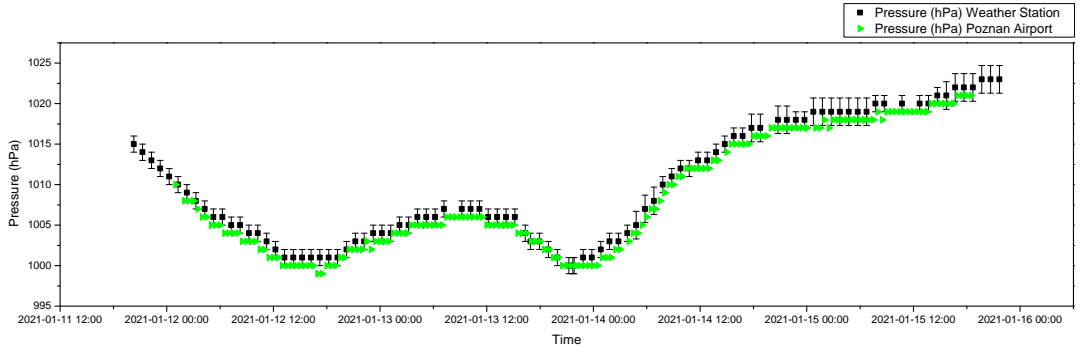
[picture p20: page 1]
Tim e

Pressu re (hPa) Weath er Stati on
Pressu re (hPa) Pozn an Ai rport

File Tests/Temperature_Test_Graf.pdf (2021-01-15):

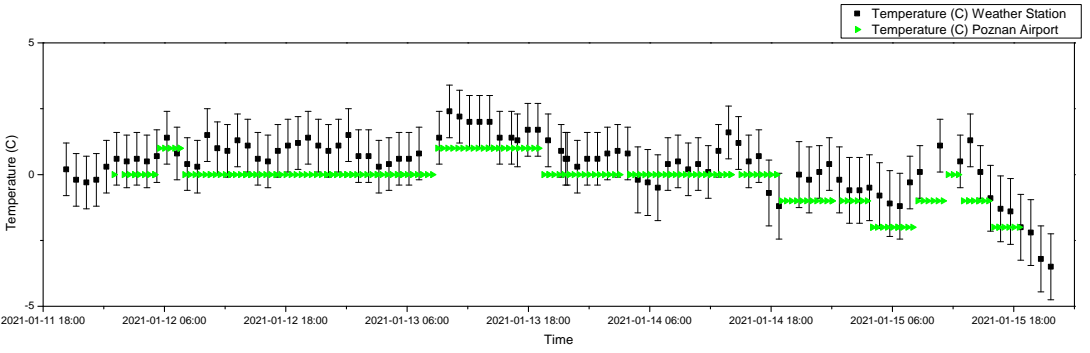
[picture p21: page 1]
Tim e

Tem peratu re (C) Weath er Stati on
Tem peratu re (C) Pozn an Ai rport

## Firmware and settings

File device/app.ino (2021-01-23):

#include <LowPower.h>
#include <Wire.h>
#include <Adafruit_BME280.h>
#include <SoftwareSerial.h>

//dev
#include <MemoryUsage.h>

//------------------System configuration--------------------------
/*If DEBUG is true, it prints answers from the modem to Serial*/
#define DEBUG true
/*If GSM is true, connect via GSM/GPRS, if false, connect via WiFi*/
#define GSM_MODE true
//Server info
const char server[] PROGMEM = {"my-application-address.com"};
int port = 80;
const char url[] PROGMEM = {"/post"};
//Wi-Fi
const char ssid_WiFI[] PROGMEM = {"my_wifi_ssid"};
const char password_WiFI[] PROGMEM = {"my_wifi_password"};
//GPRS APN - PLAY
const char gprs_apn[] PROGMEM = {"\"INTERNET\""};
//device info
const char device_name[] PROGMEM = {"my_device_name"};
const char server_password[] PROGMEM = {"my_device_password"};
//device height above sea level in in meters for calculating relative pressure
int height_above_sea_level = 80;
//---------------------------------------------------------------

//AT Commands WIFI
const char reset_WiFi[] PROGMEM = {"AT+RST"};
const char connecting_WiFi[] PROGMEM = {"AT+CWJAP_CUR=\""};

//AT Commands GSM
const char handshake[] PROGMEM = {"AT"};
const char signal_test[] PROGMEM = {"AT+CSQ"};
const char network_test[] PROGMEM = {"AT+CREG?"};
const char attach_GPRS[] PROGMEM = {"AT+CGATT=1"};
const char set_bearer_profile[] PROGMEM = {"AT+SAPBR =3,1,CONTYPE,GPRS"};
const char set_bearer_apn[] PROGMEM = {"AT+SAPBR =3,1,APN,"};
const char open_bearer[] PROGMEM = {"AT+SAPBR=1,1"};
const char query_bearer[] PROGMEM = {"AT+SAPBR=2,1"};
const char get_location[] PROGMEM = {"AT+CLBS=1,1"};
const char close_bearer[] PROGMEM = {"AT+SAPBR=0,1"};
const char detach_GPRS[] PROGMEM = {"AT+CGATT=0"};
const char cip_status[] PROGMEM = {"AT+CIPSTATUS"};
const char cip_mux[] PROGMEM = {"AT+CIPMUX=0"};
const char set_PDP[] PROGMEM = {"AT+CGDCONT=1,\"IP\","};
const char cip_apn[] PROGMEM = {"AT+CSTT="};
const char cip_gprs[] PROGMEM = {"AT+CIICR"};
const char cip_ip[] PROGMEM = {"AT+CIFSR"};
const char cip_exit_config[] PROGMEM = {"AT+CIPSHUT"};
const char sleep_gsm[] PROGMEM = {"AT+CSCLK=2"};
const char wake_up_gsm[] PROGMEM = {"AT+CSCLK=0"};

//AT Commands TCP
const char start_TCP_connection[] PROGMEM = {"AT+CIPSTART=\"TCP\",\""};
const char send_over_TCP[] PROGMEM = {"AT+CIPSEND="};

//JSON data
const char JSON_temperature[] PROGMEM = {"{\"temperature\":"};
const char JSON_pressure[] PROGMEM = {",\"pressure\":"};
const char JSON_humidity[] PROGMEM = {",\"humidity\":"};
const char JSON_battery[] PROGMEM = {",\"battery\":"};
const char JSON_pm25[] PROGMEM = {",\"pm25\":"};
const char JSON_pm10[] PROGMEM = {",\"pm10\":"};
const char JSON_uv[] PROGMEM = {",\"uv\":"};
const char JSON_device_name[] PROGMEM = {",\"name\":\""};
const char JSON_server_password[] PROGMEM = {"\",\"password\":\""};
const char JSON_latitude[] PROGMEM = {",\"latitude\":"};
const char JSON_longitude[] PROGMEM = {",\"longitude\":"};

//HTML POST header
const char HTML_POST_header_1[] PROGMEM = {"POST "};
const char HTML_POST_header_2[] PROGMEM = {" HTTP/1.1"};
const char HTML_POST_header_3[] PROGMEM = {"Host: "};
const char HTML_POST_header_4[] PROGMEM = {"Content-Type: application/json"};
const char HTML_POST_header_5[] PROGMEM = {"Content-Length: "};

String r = "\r";
String n = "\n";

byte deviceId1 = 0xFF;
byte deviceId2 = 0xFF;

#define UV A7
#define BATTERY A6
#define SDS_PIN_RX 5
#define SDS_PIN_TX 6
#if GSM_MODE
//SIM800
#define WWW_PIN_RX 8
#define WWW_PIN_TX 7
#else
//ESP
#define WWW_PIN_RX 3
#define WWW_PIN_TX 4
#endif
#define WIFIPOWER 9

#define ARRAY_SIZE 14
#define ARRAY_WASTE 4

//measurement data
float temperature;
float humidity;
float pressure;
byte uv;
float pm10;
float pm25;
float latitude;
float longitude;
int battery;

// Create BME280 object
Adafruit_BME280 bme;
// Create SoftwareSerial object
SoftwareSerial WWWSerial(WWW_PIN_RX, WWW_PIN_TX);
SoftwareSerial serialSDS(SDS_PIN_RX, SDS_PIN_TX);

void setup()
{

    analogReference(EXTERNAL);
    pinMode(WIFIPOWER, OUTPUT);
    digitalWrite(WIFIPOWER, LOW);

    bme.begin(0x76);
    Serial.begin(9600);
    WWWSerial.begin(9600);
    serialSDS.begin(9600);
    delay(15000);
    SetToQueryModeSDS();
    SleepSDS();
    sleepGSM(1000);
}

void loop()
{
    serialSDS.listen();
    WakeUpSDS();
    delay(35000);
    dataSDSquery();
    SleepSDS();

    WWWSerial.listen();
    if (DEBUG)
    {
        memoryCheck();
    }

    readSensors();

    if (GSM_MODE)
    {
        wakeUpGSM(1000);
        testGSM(1000);
        GSM_location(2000);
        startTCPconnectionGSM(2000);
        sendOverTCP(2000);
        sendData(readFromFlash(cip_exit_config) + r + n, 1000, DEBUG);
        wakeUpGSM(1000);
        sleepGSM(1000);
    }
    else
    {
        powerWiFiOn(true);
        resetWiFi(2000);
        connectWiFi(7000);
        startTCPconnection(1000);
        sendOverTCP(2000);
        powerWiFiOn(false);
    }
    for (int i = 0; i < 409; i++)
    {
        LowPower.idle(SLEEP_8S, ADC_OFF, TIMER2_OFF, TIMER1_OFF, TIMER0_OFF,
                      SPI_OFF, USART0_OFF, TWI_OFF);
        delay(50);
    }
}

void sendData(String command, int timeout, boolean debug)
{
    WWWSerial.print(command);
    unsigned long time = millis();
    while ((time + timeout) > millis())
    {
        if (debug)
        {
            while (WWWSerial.available())
            {
                char c = WWWSerial.read();
                delay(1);
                Serial.print(c);
                if (c == '\0')
                    continue;
            }
        }
    }
}

void sendDataAnswer(String command, int timeout, boolean debug)
{
    WWWSerial.print(command);
    unsigned long time = millis();
    String data;
    while ((time + timeout) > millis())
    {
        if (debug)
        {
            while (WWWSerial.available())
            {
                char c = WWWSerial.read();
                delay(1);
                Serial.print(c);
                data = data + c;
                if (c == '\0')
                    continue;
            }
        }
    }
    if (data.charAt(data.indexOf(':') + 2) == '0')
    {
        data = data.substring(data.indexOf(':') + 4, data.lastIndexOf(','));
        latitude = data.substring(data.indexOf(',') + 1).toFloat();
        longitude = data.substring(0, data.indexOf(',')).toFloat();
    }
}

void testGSM(int timeout)
{
    sendData(readFromFlash(handshake) + r + n, timeout, DEBUG);
    sendData(readFromFlash(signal_test) + r + n, timeout, DEBUG);
    sendData(readFromFlash(network_test) + r + n, timeout, DEBUG);
}
void sleepGSM(int timeout)
{
    sendData(readFromFlash(sleep_gsm) + r + n, timeout, DEBUG);
}
void wakeUpGSM(int timeout)
{
    sendData(readFromFlash(handshake) + r + n, timeout, DEBUG);
    sendData(readFromFlash(wake_up_gsm) + r + n, timeout, DEBUG);
}
void GSM_location(int timeout)
{
    sendData(readFromFlash(close_bearer) + r + n, timeout, DEBUG);
    sendData(readFromFlash(cip_exit_config) + r + n, timeout, DEBUG);
    sendData(readFromFlash(attach_GPRS) + r + n, timeout, DEBUG);
    sendData(readFromFlash(set_bearer_profile) + r + n, timeout, DEBUG);
    sendData(readFromFlash(set_bearer_apn) + readFromFlash(gprs_apn) + r + n, timeout, DEBUG);
    sendData(readFromFlash(open_bearer) + r + n, timeout, DEBUG);
    sendData(readFromFlash(query_bearer) + r + n, timeout, DEBUG);
    sendDataAnswer(readFromFlash(get_location) + r + n, 2 * timeout, DEBUG);
    sendData(readFromFlash(close_bearer) + r + n, timeout, DEBUG);
}
void startTCPconnectionGSM(int timeout)
{
    sendData(readFromFlash(cip_status) + r + n, timeout, DEBUG);
    sendData(readFromFlash(cip_mux) + r + n, timeout, DEBUG);
    sendData(readFromFlash(set_PDP) + readFromFlash(gprs_apn) + r + n, timeout, DEBUG);
    sendData(readFromFlash(cip_apn) + readFromFlash(gprs_apn) + r + n, timeout, DEBUG);
    sendData(readFromFlash(cip_gprs) + r + n, timeout, DEBUG);
    sendData(readFromFlash(cip_ip) + r + n, timeout, DEBUG);
    sendData(readFromFlash(cip_status) + r + n, timeout, DEBUG);

    String ATcommand = readFromFlash(start_TCP_connection) + readFromFlash(server) + "\"," + String(port) + r + n;
    sendData(ATcommand, timeout, DEBUG);
}
void powerWiFiOn(boolean on)
{
    if (on)
    {
        digitalWrite(WIFIPOWER, HIGH);
        delay(2000);
    }
    else
    {
        digitalWrite(WIFIPOWER, LOW);
        delay(2000);
    }
}

void connectWiFi(int timeout)
{
    String String_ssid = readFromFlash(ssid_WiFI);
    String String_password = readFromFlash(password_WiFI);
    String String_connecting_WiFi = readFromFlash(connecting_WiFi);
    String ATcommand = String_connecting_WiFi + String_ssid + "\",\"" + String_password + "\"" + r + n;
    sendData(ATcommand, timeout, DEBUG);
}

void resetWiFi(int timeout)
{
    sendData(readFromFlash(reset_WiFi) + r + n, timeout, DEBUG);
}

void startTCPconnection(int timeout)
{
    String ATcommand = readFromFlash(start_TCP_connection) + readFromFlash(server) + "\"," + String(port) + r + n;
    sendData(ATcommand, timeout, DEBUG);
}

void sendOverTCP(int timeout)
{

    int sendDataLength = POSTbodyLength_1();
    sendDataLength = sendDataLength + POSTbodyLength_2();
    sendDataLength = sendDataLength + POSTbodyLength_3();
    sendDataLength = sendDataLength + POSTbodyLength_4();
    sendDataLength = sendDataLength + JSONdataLength_1();
    sendDataLength = sendDataLength + JSONdataLength_2();
    sendDataLength = sendDataLength + JSONdataLength_3();
    sendDataLength = sendDataLength + JSONdataLength_4();
    sendDataLength = sendDataLength + JSONdataLength_5();

    sendData(readFromFlash(send_over_TCP) + String(sendDataLength) + r + n, timeout, DEBUG);

    //send body in parts
    WWWSerial.print(StringPOSTbody_1());
    WWWSerial.print(StringPOSTbody_2());
    WWWSerial.print(StringPOSTbody_3());
    WWWSerial.print(StringPOSTbody_4());
    WWWSerial.print(StringJSON_1());
    WWWSerial.print(StringJSON_2());
    WWWSerial.print(StringJSON_3());
    WWWSerial.print(StringJSON_4());
    WWWSerial.print(StringJSON_5());
    unsigned long time = millis();
    while ((time + (2 * timeout)) > millis())
    {
        if (DEBUG)
        {
            while (WWWSerial.available())
            {
                char c = WWWSerial.read();
                delay(1);
                Serial.print(c);
                if (c == '\0')
                    continue;
            }
        }
    }
}

String readFromFlash(char stringToRead[])
{
    int k;
    int len_stringToRead = strlen_P(stringToRead);
    char myChar;
    String String_stringToRead;
    for (k = 0; k < len_stringToRead; k++)
    {
        myChar = pgm_read_byte_near(stringToRead + k);
        String_stringToRead = String_stringToRead + myChar;
    }
    return String_stringToRead;
}

void readSensors()
{

    // temperature - 0; humidity - 2; pressure - 1; uv - 3; battery - 4;
    temperature = average(0);
    humidity = average(2);
    pressure = average(1);
    uv = average(3);
    battery = average(4);
}

// temperature - 0; humidity - 2; pressure; uv - 3; battery - 4;
float average(byte value)
{

    float data_array[ARRAY_SIZE];
    // reads
    for (int i = 0; i < ARRAY_SIZE; i++)
    {
        switch (value)
        {
        case 0:
            data_array[i] = bme.readTemperature();
            break;
        case 2:
            data_array[i] = bme.readHumidity();
            break;
        case 3:
            data_array[i] = readUV();
            break;
        case 4:
            data_array[i] = readBattery();
            break;
        case 1:
            float pressure_real = (bme.readPressure() / 100.0F);
            data_array[i] = pressure_real + (height_above_sea_level / (8000 * ((1 + (0.004 * temperature)) / pressure_real)));
            break;
        }
        delay(100);
    }

    //sort
    sort(data_array, ARRAY_SIZE);

    float result = 0;
    for (int i = (ARRAY_WASTE / 2); i < ARRAY_SIZE - (ARRAY_WASTE / 2); i++)
    {
        result = result + data_array[i];
    }
    result = result / (ARRAY_SIZE - (ARRAY_WASTE));

    return result;
}
void sort(float a[], int size)
{
    for (int i = 0; i < (size - 1); i++)
    {
        for (int o = 0; o < (size - (i + 1)); o++)
        {
            if (a[o] > a[o + 1])
            {
                float t = a[o];
                a[o] = a[o + 1];
                a[o + 1] = t;
            }
        }
    }
}

byte readUV()
{
    word value = analogRead(UV);
    if (value > 220)
    {
        return 11;
    }
    else if (value > 199)
    {
        return 10;
    }
    else if (value > 180)
    {
        return 9;
    }
    else if (value > 164)
    {
        return 8;
    }
    else if (value > 142)
    {
        return 7;
    }
    else if (value > 124)
    {
        return 6;
    }
    else if (value > 103)
    {
        return 5;
    }
    else if (value > 83)
    {
        return 4;
    }
    else if (value > 65)
    {
        return 3;
    }
    else if (value > 46)
    {
        return 2;
    }
    else if (value > 10)
    {
        return 1;
    }
    else
    {
        return 0;
    }
}

int readBattery()
{
    int value = analogRead(BATTERY);
    return (int)(((value * 5.0) / 1024.0) * 1000);
}

String StringJSON_1()
{
    String JSONdata =
        readFromFlash(JSON_temperature) + String(temperature) +
        readFromFlash(JSON_pressure) + String(pressure);
    return JSONdata;
}
String StringJSON_2()
{
    String JSONdata =
        readFromFlash(JSON_humidity) + String(humidity) +
        readFromFlash(JSON_battery) + String(battery);
    return JSONdata;
}
String StringJSON_3()
{
    String JSONdata =
        readFromFlash(JSON_pm25) + String(pm25) +
        readFromFlash(JSON_pm10) + String(pm10) +
        readFromFlash(JSON_uv) + String(uv);
    return JSONdata;
}
String StringJSON_4()
{
    char buff_latitude[10];
    char buff_longitude[10];
    dtostrf(latitude, 4, 4, buff_latitude);
    dtostrf(longitude, 4, 4, buff_longitude);
    String JSONdata =
        readFromFlash(JSON_latitude) + buff_latitude +
        readFromFlash(JSON_longitude) + buff_longitude;
    return JSONdata;
}
String StringJSON_5()
{
    String JSONdata =
        readFromFlash(JSON_device_name) + readFromFlash(device_name) +
        readFromFlash(JSON_server_password) + readFromFlash(server_password) + "\"}";
    return JSONdata;
}

int JSONdataLength_1()
{
    return StringJSON_1().length();
}
int JSONdataLength_2()
{
    return StringJSON_2().length();
}
int JSONdataLength_3()
{
    return StringJSON_3().length();
}
int JSONdataLength_4()
{
    return StringJSON_4().length();
}
int JSONdataLength_5()
{
    return StringJSON_5().length();
}

String StringPOSTbody_1()
{
    String POSTbody =
        readFromFlash(HTML_POST_header_1) + readFromFlash(url) + //"POST "
        readFromFlash(HTML_POST_header_2) + r + n;               //" HTTP/1.1"
    return POSTbody;
}

String StringPOSTbody_2()
{
    String POSTbody =
        readFromFlash(HTML_POST_header_3) + readFromFlash(server) + r + n; //"Host: "
    return POSTbody;
}
String StringPOSTbody_3()
{
    String POSTbody =
        readFromFlash(HTML_POST_header_4) + r + n; //"Content-Type: application/json"
    return POSTbody;
}
String StringPOSTbody_4()
{
    int JSONdataLength = (JSONdataLength_1() + JSONdataLength_2() + JSONdataLength_3() + JSONdataLength_4() + JSONdataLength_5());
    String POSTbody =
        readFromFlash(HTML_POST_header_5) + JSONdataLength + r + n + r + n; //"Content-Length: "
    return POSTbody;
}

int POSTbodyLength_1()
{
    return StringPOSTbody_1().length();
}

int POSTbodyLength_2()
{
    return StringPOSTbody_2().length();
}

int POSTbodyLength_3()
{
    return StringPOSTbody_3().length();
}
int POSTbodyLength_4()
{
    return StringPOSTbody_4().length();
}

void memoryCheck()
{
    Serial.println();
    FREERAM_PRINT;
    Serial.println();
}
//------Dust sensor functions---------------------------------------------------
void QueryModeSDS()
{
    sendSDS(0x02, false, false);
}
void SetToQueryModeSDS()
{
    sendSDS(0x02, true, true);
}
void SetToActiveModeSDS()
{
    sendSDS(0x02, true, false);
}
void QuerySleepSDS()
{
    sendSDS(0x06, false, false);
}
void SleepSDS()
{
    sendSDS(0x06, false, true);
}
void WakeUpSDS()
{
    sendSDS(0x06, true, true);
}
void dataSDSquery()
{
    sendSDS(0x04, false, false);
    Serial.println(pm25);
    Serial.println(pm10);
}
void sendSDS(byte commandId, boolean condition, boolean activeMode)
{
    byte SDS_cmd[] = {0xAA, 0xB4, commandId, 0x00, 0x00, 0x00, 0x00, 0x00, 0x00, 0x00, 0x00, 0x00, 0x00, 0x00, 0x00, deviceId1, deviceId2, 0x00, 0xAB};
    switch (commandId)
    {
    case (0x02): //set data mode
        if (condition)
        { // condition - true - set, false - query
            SDS_cmd[3] = 0x01;
        }
        if (activeMode)
        { // activeMode - true - active , false - query
            SDS_cmd[4] = 0x01;
        }
        break;
    case (0x06): //sleep -wakeup
        if (activeMode)
        { // activeMode - true - - active , false - query
            SDS_cmd[3] = 0x01;
        }
        if (condition)
        { // condition - true - wake up, false - sleep
            SDS_cmd[4] = 0x01;
        }
        break;
    }

    int checksum = 0;
    for (int i = 2; i <= 16; i++)
    {
        checksum = checksum + SDS_cmd[i];
    }
    checksum = checksum % 0x100;
    SDS_cmd[17] = checksum;

    if (DEBUG)
    {
        for (int i = 0; i < 19; i++)
        {
            Serial.print(SDS_cmd[i], HEX);
            Serial.print(" ");
        }
        Serial.println(" ");
    }
    byte b;
    int len = 0;
    int value;
    int pm10_serial = 0;
    int pm25_serial = 0;
    delay(100);
    serialSDS.write(SDS_cmd, sizeof(SDS_cmd));
    delay(100);
    while (serialSDS.available() > 0)
    {
        b = serialSDS.read();
        value = int(b);

        if (DEBUG)
        {
            Serial.print(String(value, HEX) + " ");
        }
        if (commandId == 0x04)
        {
            switch (len)
            {
            case (2):
                pm25_serial = value;
                break;
            case (3):
                pm25_serial = pm25_serial + (value << 8);
                break;
            case (4):
                pm10_serial = value;
                break;
            case (5):
                pm10_serial = pm10_serial + (value << 8);
                break;
            }
        }
        len++;
    }
    if (DEBUG)
    {
        Serial.println("");
    }
    if (commandId == 0x04)
    {
        pm10 = (float)pm10_serial / 10.0;
        pm25 = (float)pm25_serial / 10.0;
    }
}

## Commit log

2020-07-21 initial device
2020-07-23 Set device to send POST (HTTP) to server
2020-09-27 add new components, modify chart,add support for multiple devices in server, db and client.
2020-12-21 add powerSaving and dust sensor functions
2021-01-06 add STL File
    [Weather_Station_ Body.stl, Weather_Station_ Roof.stl, Weather_Station_Door.stl]
2021-01-06 add 3d model and png file
    [Weather_Station.skp]
2021-01-06 add wiring diagrams
2021-01-09 new STL file
    [Weather_Station_ Body.stl, Weather_Station_ Roof.stl, Weather_Station_Door.stl]
2021-01-09 test file
    [Weather_Station_ Body_1.stl]
2021-01-09 correct stl file
    [Weather_Station_ Body.stl, Weather_Station_ Body_1.stl, Weather_Station_ Roof.stl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]
2021-01-13 STL file mod
    [Weather_Station_ Body.stl, Weather_Station_ Roof.stl, Weather_Station_Door.stl]
2021-01-15 Add BME280 test file
    [Measurement uncertainty.xlsx]
2021-01-23 add assembly images
2021-03-27 button text
